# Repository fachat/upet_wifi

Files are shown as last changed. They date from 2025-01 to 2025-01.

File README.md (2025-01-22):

# Wifi breakout module for Micro-PET 3.x, Ultra-CPU 2.x, and Ulti-PET 1.x

This is part of a larger project with multiple boards, with [upet_family](https://github.com/fachat/upet_family) as parent repository.

This module implements a Wifi module for the [Micro-PET](https://github.com/fachat/cbm_micropet), the [Ultra-CPU](https://github.com/fachat/csa_ultracpu), and the [Ulti-PET](https://github.com/fachat/cbm_ultipet). These boards provide an SPI-based breakout connector, which this module plugs in to.

The Wifi-Module used is an ESP32-C3-WROOM-02 module that uses two serial (rs232 on 3.3V TTL level) interfaces - one for firmware updates and logs, the other for the AT commands used to control the communication.
To connect to the main board, this breakout board uses a dual-UART SC16IS752 that has an SPI interface to control it.

## Build

This repository contains the KiCad schematics and PCB layout, as well as gerber files (gerbers directory). and the interactive BOM (bom directory).
Also, in the bom directory is a full XLSX format BOM with manufacturer and Mouser and JLCPCB part numbers, that you can upload to your favourite parts provider.

[Schematics PDF](UPET-Wifi-Schematics.pdf)
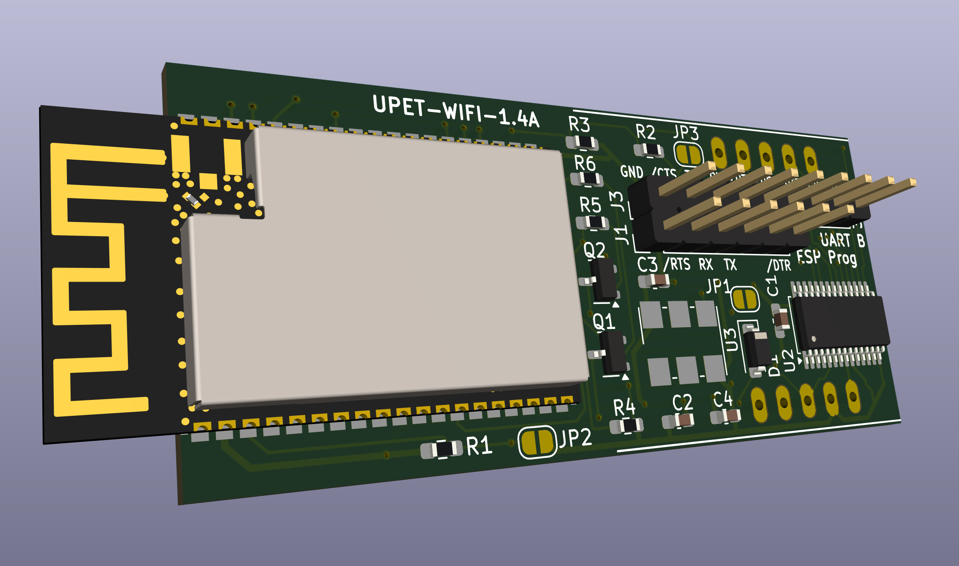
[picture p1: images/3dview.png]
3D view of the board


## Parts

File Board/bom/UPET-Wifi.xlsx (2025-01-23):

Id | Designator | Footprint | Quantity | Designation | Supplier and ref | MOUSER | Manufact. Part | JLCPCB
1 | C3,C1,C2 | C_0603_1608Metric_Pad1.08x0.95mm_HandSolder | 3 | 0.1u |  | 710-885012206020 | 885012206020 | C14663
6 | C4 | C_0603_1608Metric_Pad1.08x0.95mm_HandSolder | 1 | 10u |  | 187-CL10A106KQ8NNNL | CL10A106KQ8NNN | C19702
 | D1 | SOD-123 | 1 | 1N4148W |  | 78-1N4148W-HE3_A-18 | 1N4148W-HE3_A-18 | C5443965
 | J1 | PinHeader_1x06_P2.54mm_Vertical
 | J3 | PinHeader_1x09_P2.54mm_Vertical
 |  |  | 2 |  |  | 649-1012937892001BLF | 10129378-920001BLF
 | Q1, Q2 | SOT-23 | 2 | S8050 |  | 833-MMSS8050-H-TP | MMSS8050-H-TP | C181158
5 | R1,R4 | R_0603_1608Metric_Pad0.98x0.95mm_HandSolder | 2 | 10k |  | 660-SG73S1JTTD103J | SG73S1JTTD103J | C17414
 | R2 | 603 | 1 | 1k |  | 652-CR0603AFX1001ELF | CR0603AFX-1001ELF | C21190
 | R3 | 603 | 1 | 1k5 |  | 708-RMCF0603JT1K50 | RMCF0603JT1K50 | C2907083
 | R5, R6 | 603 | 2 | 12k |  | 660-RK73B1JTTDD123J | RK73B1JTTDD123J | C22790
2 | U4 | ESP32-WROVER-E-N16R8 | 1 | ESP32-WROVER-E-N16R8 |  | 356-ESP32WRVE22864PC | ESP32-WROVER-E-N16R8 | C529589
3 | U2 | TSSOP-28_4.4x9.7mm_P0.65mm | 1 | SC16IS752IPW |  | 771-SC16IS752IPW | SC16IS752IPW,112 | C57156
7 | U3 | Oscillator_SMD_IDT_JU6-6_7.0x5.0mm_P2.54mm | 1 | 1.8432 MHz |  | 972-LH736001.843200I | XLH736001.843200I | C2901464

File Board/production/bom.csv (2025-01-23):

Designator | Footprint | Quantity | Value | LCSC Part #
C1, C2, C3 | 0603 | 3 | 0.1u
C4 | 0603 | 1 | 10u
D1 | D_SOD-123 | 1 | 1N4148W
J1 | PinHeader_1x06_P2.54mm_Vertical | 1 | Conn_01x06
J3 | PinHeader_1x09_P2.54mm_Vertical | 1 | Conn_01x09
Q1, Q2 | SOT-23 | 2 | S8050
R1, R4 | 0603 | 2 | 10k
R2 | 0603 | 1 | 1k
R3 | 0603 | 1 | 1k5
R5, R6 | 0603 | 2 | 12k
U$1 | UPET_NETSPI | 1 | uPET NET SPI
U2 | TSSOP-28_4.4x9.7mm_P0.65mm | 1 | SC16IS752IPW
U3 | Oscillator_SMD_IDT_JU6-6_7.0x5.0mm_P2.54mm | 1 | 1.8432 MHz
U4 | ESP32-WROVER-E | 1 | ESP32-WROVER-E

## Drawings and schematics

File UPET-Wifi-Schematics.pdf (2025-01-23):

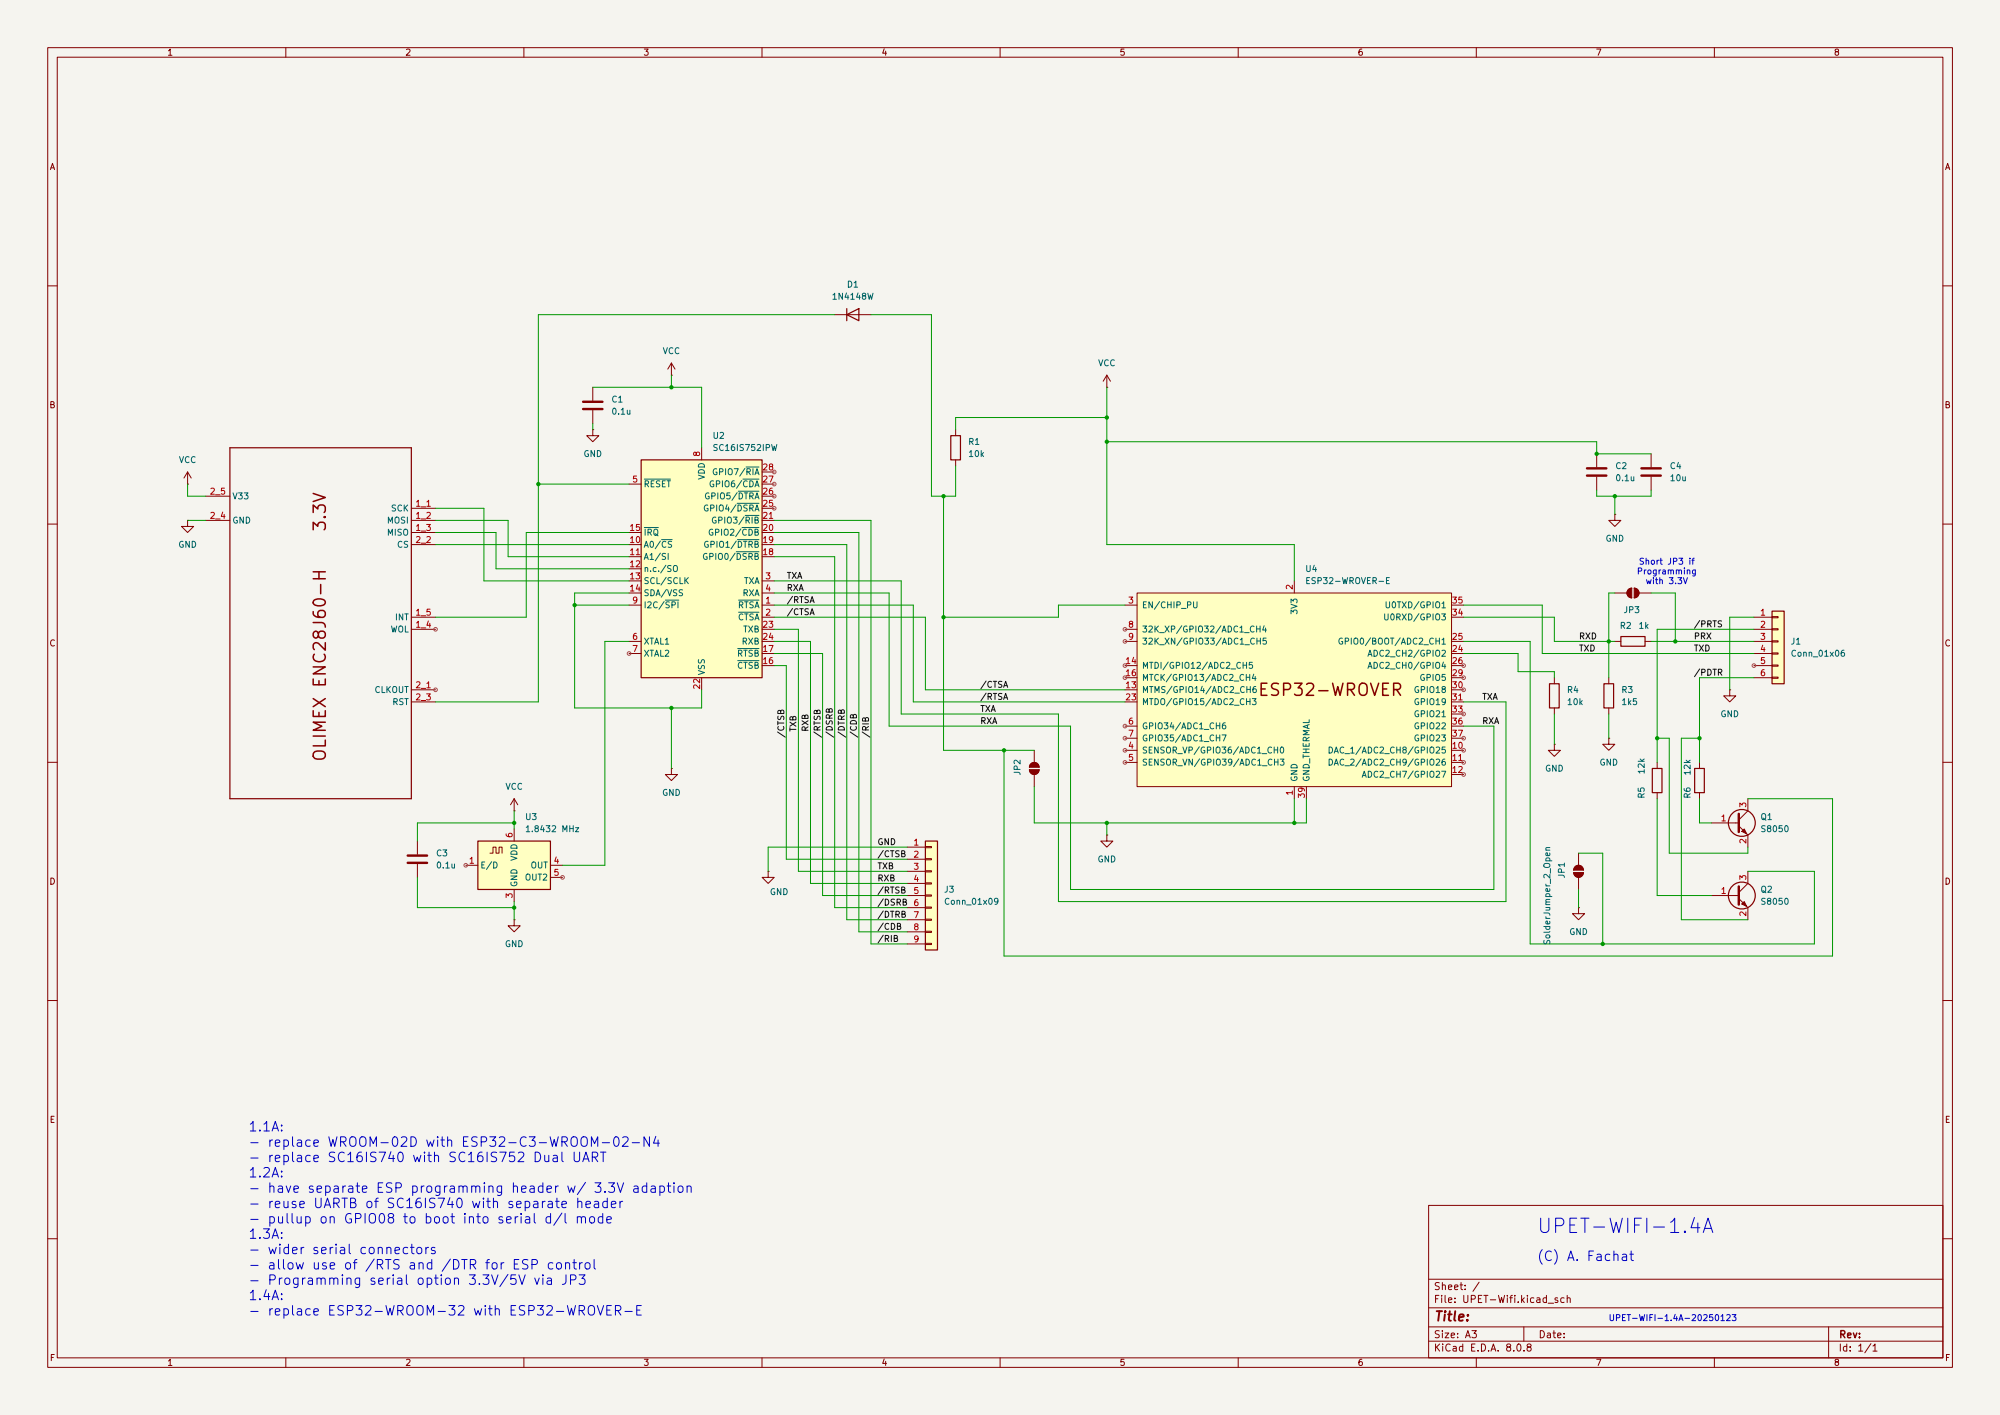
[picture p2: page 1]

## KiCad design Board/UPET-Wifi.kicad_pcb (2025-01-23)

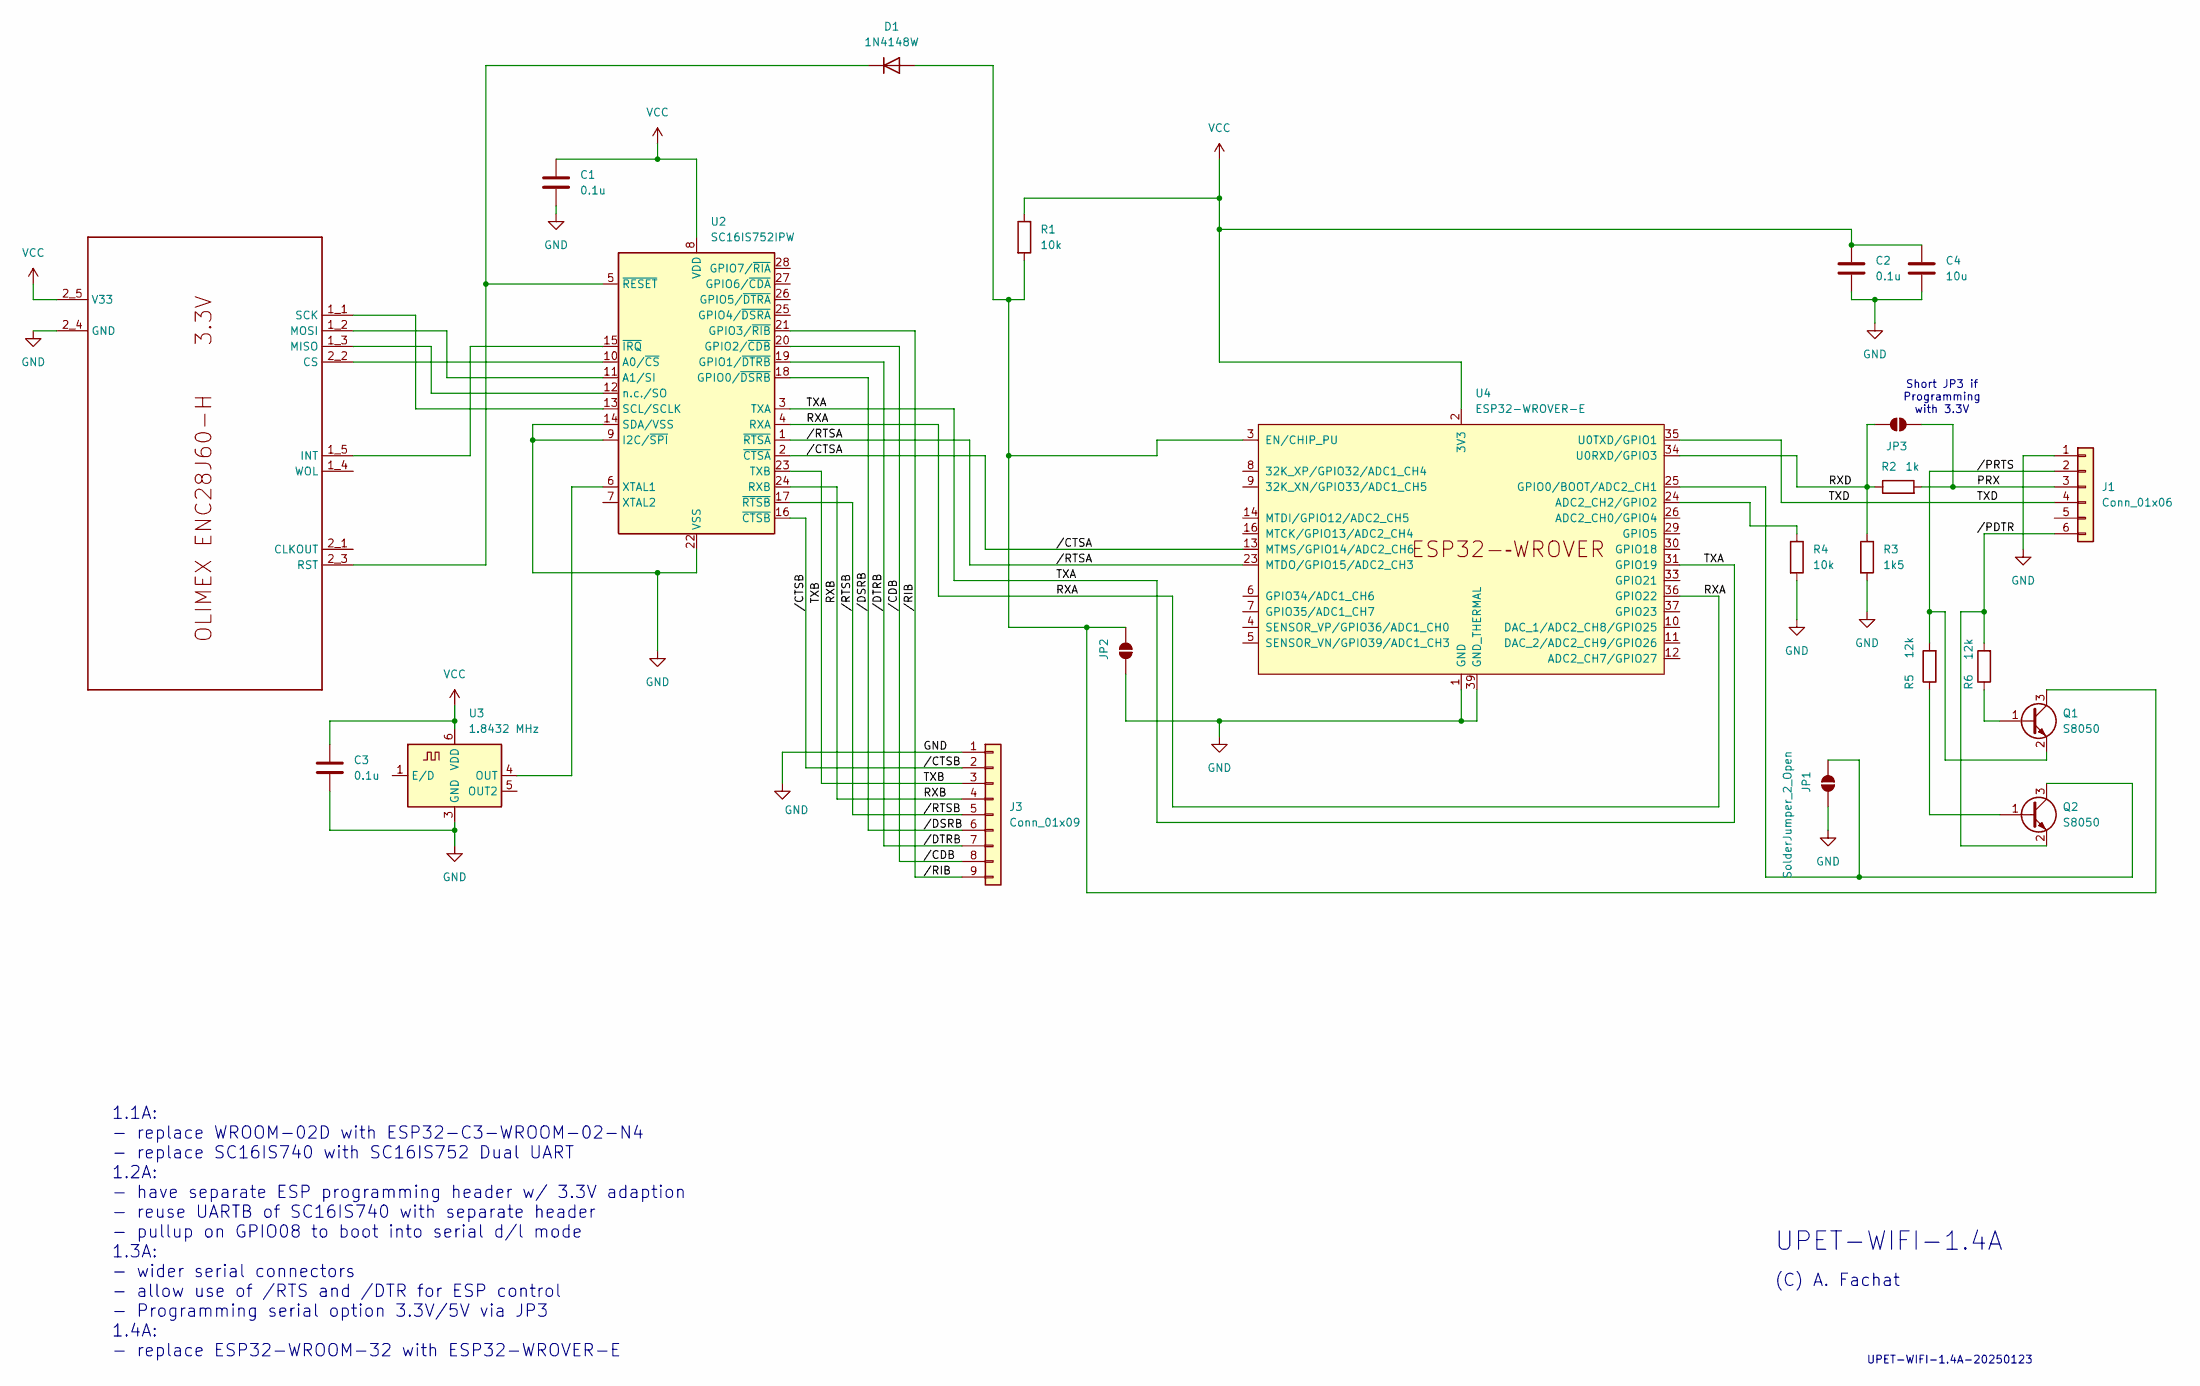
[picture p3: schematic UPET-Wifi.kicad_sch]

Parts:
C1, C2, C3: 0.1u; C_0603_1608Metric_Pad1.08x0.95mm_HandSolder
C4: 10u; C_0603_1608Metric_Pad1.08x0.95mm_HandSolder
D1: 1N4148W; D_SOD-123
J1: Conn_01x06; PinHeader_1x06_P2.54mm_Vertical
J3: Conn_01x09; PinHeader_1x09_P2.54mm_Vertical
JP1, JP2, JP3: SolderJumper_2_Open; SolderJumper-2_P1.3mm_Open_RoundedPad1.0x1.5mm
Q1, Q2: S8050; SOT-23
R1, R4: 10k; R_0603_1608Metric_Pad0.98x0.95mm_HandSolder
R2: 1k; R_0603_1608Metric_Pad0.98x0.95mm_HandSolder
R3: 1k5; R_0603_1608Metric_Pad0.98x0.95mm_HandSolder
R5, R6: 12k; R_0603_1608Metric_Pad0.98x0.95mm_HandSolder
U2: SC16IS752IPW; TSSOP-28_4.4x9.7mm_P0.65mm
U3: 1.8432 MHz; Oscillator_SMD_IDT_JU6-6_7.0x5.0mm_P2.54mm
U4: ESP32-WROVER-E
U$1: uPET NET SPI; UPET_NETSPI

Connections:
/PRX: J1.3, JP3.1 (A), R2.2
/RXA: U2.4 (RXA), U4.36 (GPIO22)
/RXB: J3.4, U2.24 (RXB)
/RXD: JP3.2 (B), R2.1, R3.1, U4.34 (U0RXD/GPIO3)
/TXA: U2.3 (TXA), U4.31 (GPIO19)
/TXB: J3.3, U2.23 (TXB)
/TXD: J1.4, U4.35 (U0TXD/GPIO1)
//CDB: J3.8, U2.20 (GPIO2/~CDB)
//CTSA: U2.2 (~CTSA), U4.13 (MTMS/GPIO14/ADC2_CH6)
//CTSB: J3.2, U2.16 (~CTSB)
//DSRB: J3.6, U2.18 (GPIO0/~DSRB)
//DTRB: J3.7, U2.19 (GPIO1/~DTRB)
//PRTS: J1.2, Q1.2 (E), R5.2
//RIB: J3.9, U2.21 (GPIO3/~RIB)
//RTSA: U2.1 (~RTSA), U4.23 (MTDO/GPIO15/ADC2_CH3)
//RTSB: J3.5, U2.17 (~RTSB)
GND: C1.2, C2.2, C3.2, C4.2, J1.1, J3.1, JP1.1 (A), JP2.1 (A), R3.2, R4.2, U2.9 (I2C/~SPI), U2.14 (SDA/VSS), U2.22 (VSS), U3.3 (GND), U4.1 (GND), U4.15 (GND), U4.38 (GND), U4.39 (GND_THERMAL), U$1.2_4 (GND)
unnamed: D1.2 (A), JP2.2 (B), Q1.3 (C), R1.2, U4.3 (EN/CHIP_PU)
unnamed: D1.1 (K), U2.5 (~RESET), U$1.2_3 (RST)
unnamed: J1.6, Q2.2 (E), R6.2
unnamed: JP1.2 (B), Q2.3 (C), U4.25 (GPIO0/BOOT/ADC2_CH1)
unnamed: Q1.1 (B), R6.1
unnamed: Q2.1 (B), R5.1
unnamed: U2.6 (XTAL1), U3.4 (OUT)
unnamed: R4.1, U4.24 (ADC2_CH2/GPIO2)
unnamed: U2.10 (A0/~CS), U$1.2_2 (CS)
unnamed: U2.15 (~IRQ), U$1.1_5 (INT)
unnamed: U2.12 (n.c./SO), U$1.1_3 (MISO)
unnamed: U2.11 (A1/SI), U$1.1_2 (MOSI)
unnamed: U2.13 (SCL/SCLK), U$1.1_1 (SCK)
VCC: C1.1, C2.1, C3.1, C4.1, R1.1, U2.8 (VDD), U3.6 (VDD), U4.2 (3V3), U$1.2_5 (V33)

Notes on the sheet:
(C) A. Fachat
1.1A: - replace WROOM-02D with ESP32-C3-WROOM-02-N4 - replace SC16IS740 with SC16IS752 Dual UART 1.2A: - have separate ESP programming header w/ 3.3V adaption - reuse UARTB of SC16IS740 with separate header - pullup on GPIO08 to boot into serial d/l mode 1.3A: - wider serial connectors - allow use 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
Short JP3 if Programming with 3.3V
UPET-WIFI-1.4A
UPET-WIFI-1.4A-20250123

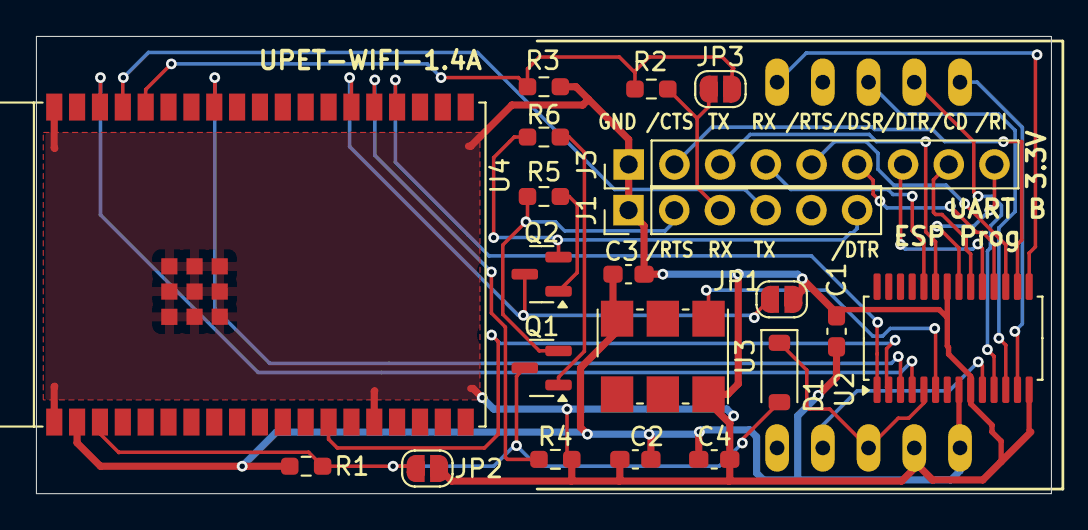
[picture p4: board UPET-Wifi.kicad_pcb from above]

Board: 2 copper layers, 56.4 x 25.4 mm, 22 parts (0 on the bottom side), 31 nets.

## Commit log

2024-06-18 initial commit upet-wifi 1.1a
    [Baudrates.ods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]
2024-06-20 cleanup, move files
    [UPET-Wifi-B_Cu.gbl, UPET-Wifi-B_Mask.gbs, UPET-Wifi-B_Paste.gbp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]
2024-09-03 move to 1.2 - separate serial prog interface
    [UPET-Wifi-B_Cu.gbl, UPET-Wifi-B_Mask.gbs, UPET-Wifi-B_Paste.gbp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]
2025-01-19 work on wifi 1.3a
    [UPET-Wifi.kicad_pcb, UPET-Wifi.kicad_sch]
2025-01-19 gerbers, bom, etc
    [UPET-Wifi.kicad_pcb, bom.csv, designators.csv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]
2025-01-22 production files
    [UPET-Wifi.kicad_pcb, UPET-Wifi.kicad_sch, designators.csv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]
2025-01-22 remove board pdf
2025-01-23 replace ESP32-WROOM with an ESP32-VROVER-E
    [UPET-Wifi.kicad_pcb, UPET-Wifi.kicad_sch, bom.csv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]
2025-01-23 update bom
    [UPET-Wifi.xlsx]
